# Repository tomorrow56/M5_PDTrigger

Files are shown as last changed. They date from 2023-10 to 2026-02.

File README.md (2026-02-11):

# PD Trigger Module for M5Stack

**[English Version](README_EN.md)**

## 概要

このモジュールは、USB PD（Power Delivery）プロトコルに対応した電源から電力を供給し、電流を監視・制御するためのM5Stack Core/Core2用の拡張モジュールです。
M-Busに接続することで、USB PD対応電源からの電力供給と電流監視を可能にします。

### プリント基板

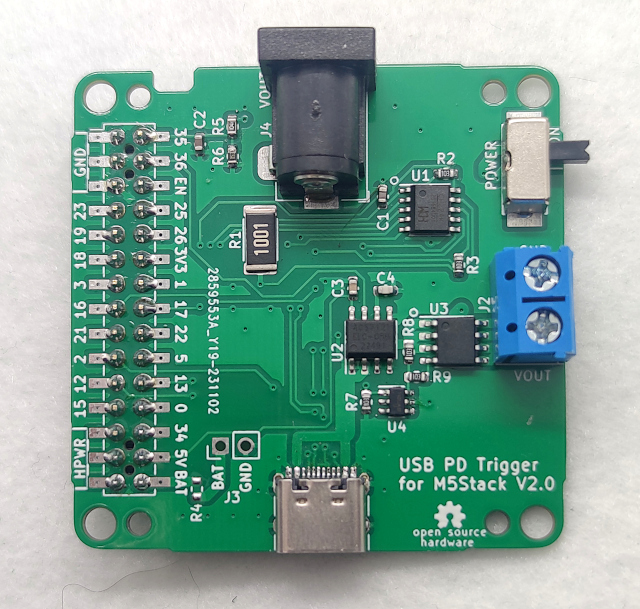
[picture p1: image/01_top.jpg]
Top View

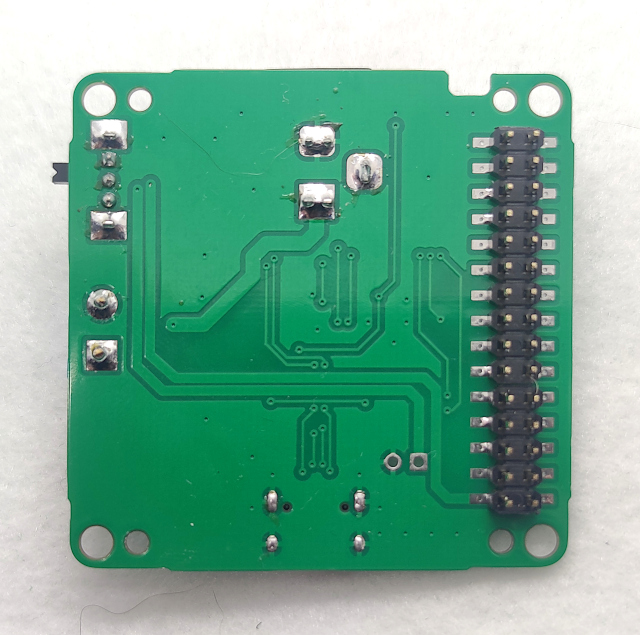
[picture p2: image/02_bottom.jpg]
Bottom View


## 主な機能

### USB PD対応充電器やモバイルバッテリーからの任意電圧の取り出し

WCH社のUSB PDシンクIC 「CH224K」を使用、M5Stack Basic/Core2のM-Busに接続して充電器のPDOに応じて「5V/9V/12V/15V/20V」が取り出せます。(注: PPSには未対応です。)

### 出力電流の測定

ALLEGRO社のホール電流センサIC「ACS712」を搭載し、出力電流が測定出来ます。

### 出力制御

Power Mos FETを用いて、M5Stackのプログラムから出力ON/OFFを制御できます。

### 回路図

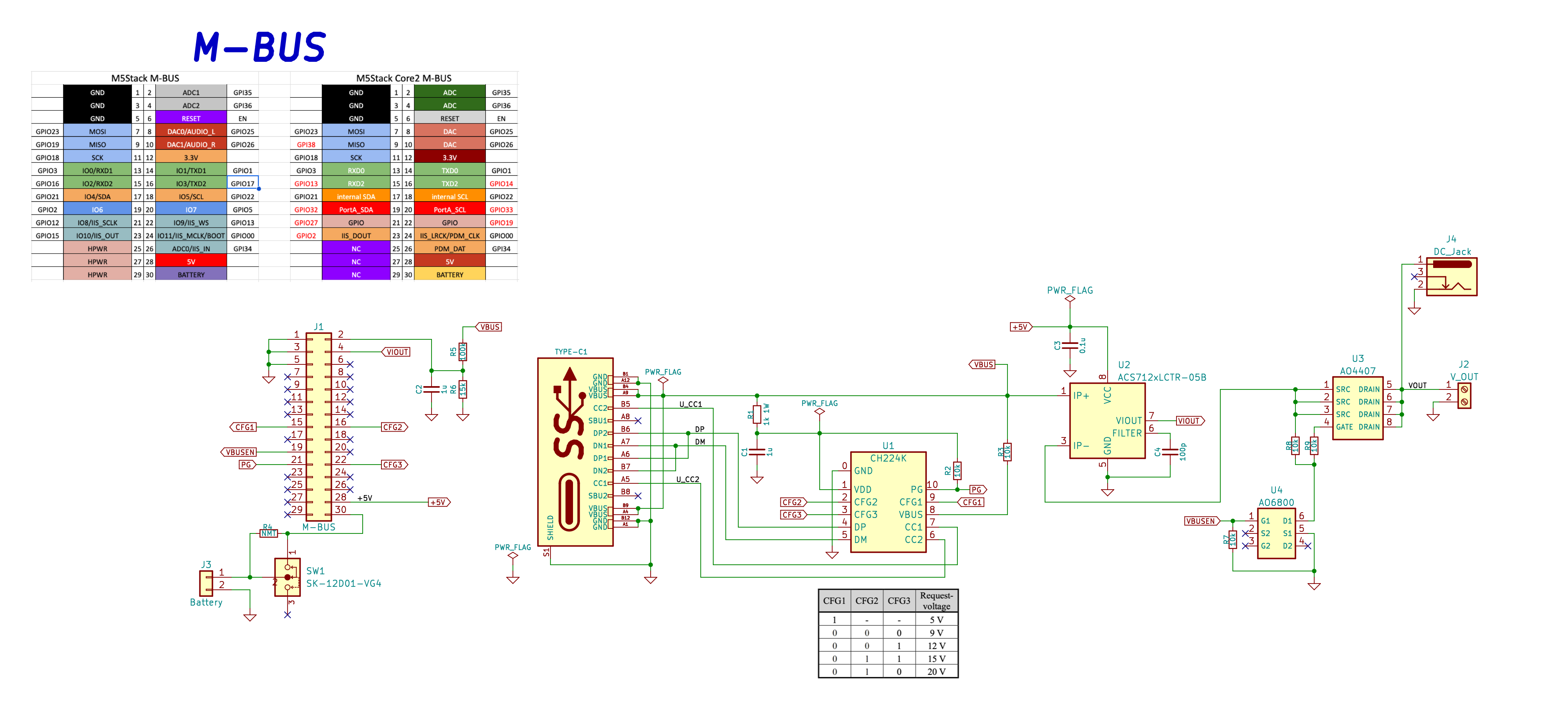
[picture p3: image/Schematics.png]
Schematic


## 使用している主要部品のデータシート

### USB PD Sink IC
[WCH CH224K](https://datasheet.lcsc.com/lcsc/2204251615_WCH-Jiangsu-Qin-Heng-CH224K_C970725.pdf)

### Hall Effect-Based Linear Current Sensor IC
[Allegro ACS712ELCTR-05B-T](https://datasheet.lcsc.com/lcsc/1811061527_Allegro-MicroSystems--LLC-ACS712ELCTR-05B-T_C44471.pdf)

### P-Channel MOSFET
[KEXIN AO4407](https://datasheet.lcsc.com/lcsc/1912111437_KEXIN-AO4407_C382328.pdf)

### Dual N-Channel MOSFET
[UMW AO6800](https://datasheet.lcsc.com/lcsc/2304120930_UMW-Youtai-Semiconductor-Co---Ltd--AO6800_C5375979.pdf)

## フォルダ構成

```text
M5_PDTrigger/
├── README.md              # プロジェクト説明
├── LICENSE                # MITライセンス
├── .gitignore            # Git除外ファイル
├── bom/                  # 部品表
│   └── M5_PDTrigger_BOM.csv
├── case/                 # 3Dプリント用ケース
│   └── PDtrigger_10mm_DC.stl
├── examples/             # サンプルコード
│   ├── M5_PDtrigger_test/
│   │   └── M5_PDtrigger_test.ino
│   └── M5Core2_PDtrigger_test/
│       └── M5Core2_PDtrigger_test.ino
├── image/                # 画像ファイル
│   ├── 01_top.jpg        # 基板表面
│   ├── 02_bottom.jpg     # 基板裏面
│   ├── 03_case_1.jpg     # ケース上面
│   ├── 04_case_2.jpg     # ケース下面
│   ├── 05_terminal.jpg   # 出力端子
│   ├── Sample_basic.jpg  # Basic動作例
│   ├── Sample_core2.jpg  # Core2動作例
│   ├── M5_PDTrigger_BOM.png
│   └── Schematics.png
└── schematics/           # 回路図
    └── M5PD_ch224k_sch.pdf
```

## サンプルコード

M5Stack Basic/Core用のサンプルコードです。以下の機能を実装しています：

### M5Stack Basic用サンプル

- **電圧切り替え**: ボタンA/Cで5V/9V/12V/15V/20VのPDOを切り替え
- **出力制御**: ボタンBで出力ON/OFFを制御  
- **電流電圧監視**: ACS712で電流を、ADコンバータで電圧を測定
- **PG監視**: Power Good信号の状態を表示

**ピン配置**:
```cpp
#define VBUS_I          35    // 電圧測定
#define VI_I            36    // 電流測定  
#define CFG1_O          16    // PD設定1
#define CFG2_O          17    // PD設定2
#define CFG3_O          13    // PD設定3
#define VBUSEN_O         2    // 出力イネーブル
#define PG_I            12    // Power Good入力
```

**操作方法**:
- ボタンA: PDO電圧を下げる
- ボタンB: 出力ON/OFF切り替え
- ボタンC: PDO電圧を上げる

**M5Stack Basicの動作例**:

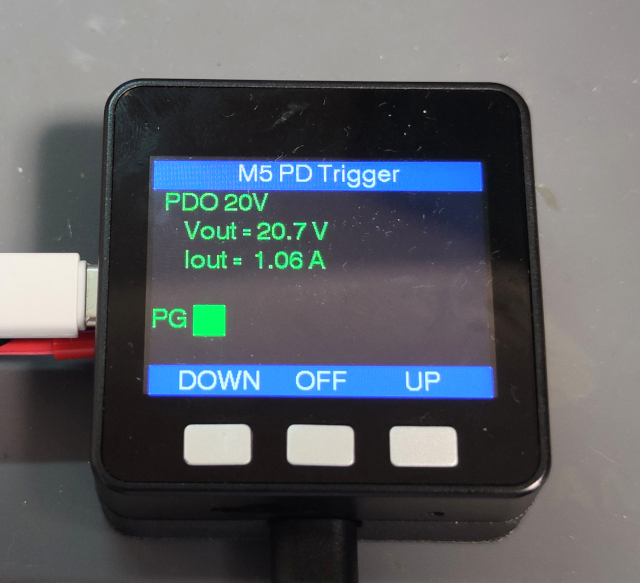
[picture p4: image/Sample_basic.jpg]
Sample_basic


### M5Stack Core2用サンプル

M5Stack Core2用のサンプルコードです。Basic版と同様の機能ですが、ピン配置が異なります：

**ピン配置**:
```cpp
#define VBUS_I          35    // 電圧測定
#define VI_I            36    // 電流測定
#define CFG1_O          13    // PD設定1  
#define CFG2_O          14    // PD設定2
#define CFG3_O          19    // PD設定3
#define VBUSEN_O        32    // 出力イネーブル
#define PG_I            27    // Power Good入力
```
**M5Stack Core2の動作例**:

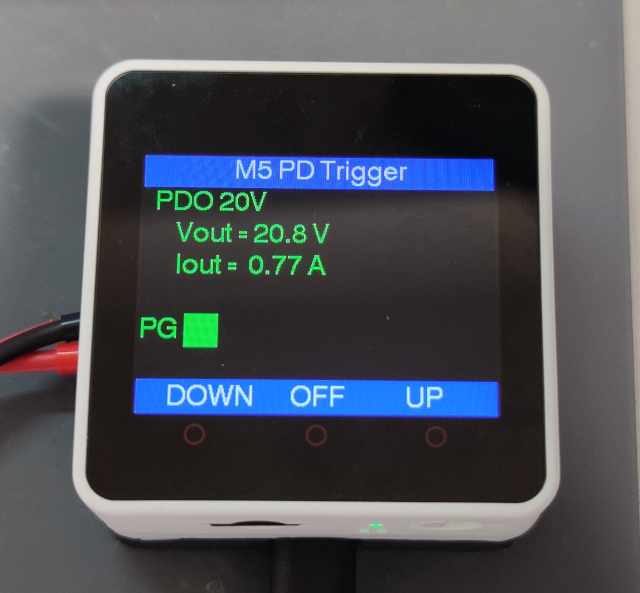
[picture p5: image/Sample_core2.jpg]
Sample_core2


**キャリブレーション**:

* 出力OFFの時に自動で0Aの補正を行います。
* ADコンバータのバラツキを補正するためのキャリブレーションパラメータがありますので、正確な値が必要な場合は実際の測定値を元に調整してください：

```cpp
float vScale = 7.83;     // 電圧スケール係数
float vi_0A = 2.44;      // 0A時の電流センサ出力電圧
float vi_2A = 2.85;      // 2A時の電流センサ出力電圧
```

## ケースに入れた状態

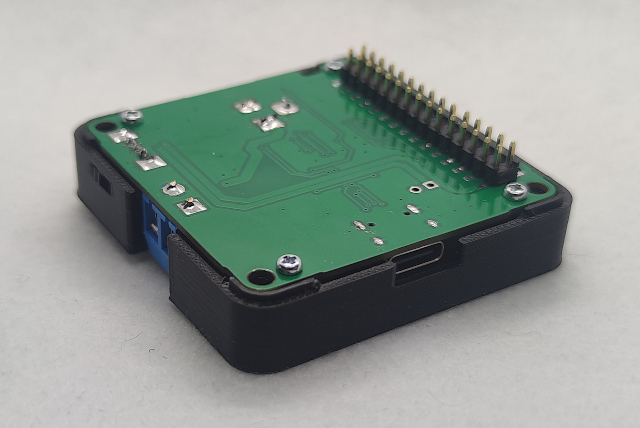
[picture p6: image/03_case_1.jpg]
case_top


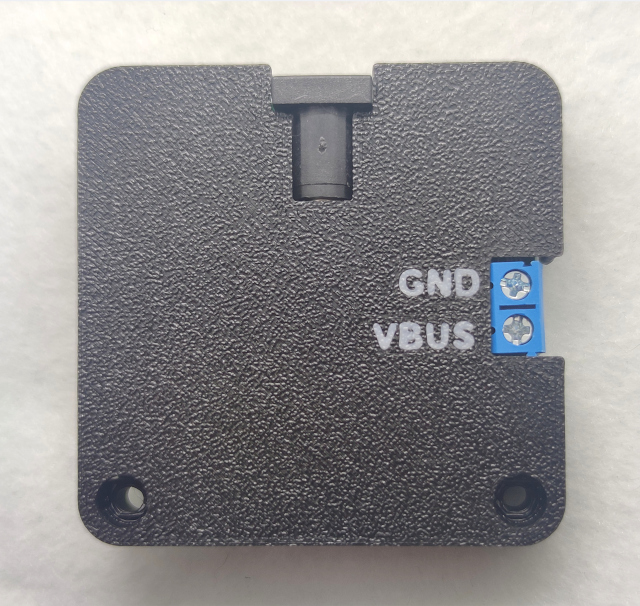
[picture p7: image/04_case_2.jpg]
case_bottom


### 出力端子

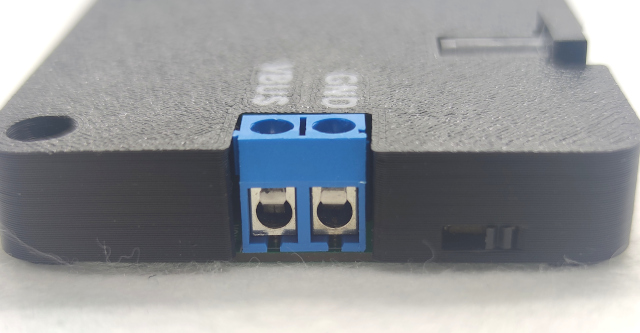
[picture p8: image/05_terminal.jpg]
output_terminals


## ライセンス

本プロジェクトはMITライセンスの下で公開されています。詳細はLICENSEファイルを参照してください。

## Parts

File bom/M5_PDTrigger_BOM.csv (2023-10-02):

No. | Name | フットプリント | 員数 | Type/Name | Link
C1,C2 | チップキャパシタ m1608(i0603) | C_0603_1608Metric | 2 | 1u
C3 | チップキャパシタ m1608(i0603) | C_0603_1608Metric | 1 | 0.1u
C4 | チップキャパシタ m1608(i0603) | C_0603_1608Metric | 1 | 100p
D1 | ショットキーバリアダイオード 40V3A | D_SMA | 1 | NMT | https://akizukidenshi.com/catalog/g/gI-06124/
J1 | ロープロファイルピンヘッダ 2×20(40P) 7.7mm | Pin_Header_MBUS_SMD_TH | 1 | M-BUS | https://akizukidenshi.com/catalog/g/gC-10460/
J2 | ターミナルブロック 2P 青 縦 小 | TB111-2-2 | 1 | TB111-2-2-U-1-1 | https://akizukidenshi.com/catalog/g/gP-01306/
J3 | LiPo接続用 | PinHeader_1x02_P2.54mm_Horizontal | 1 | NMT | https://akizukidenshi.com/catalog/g/gC-15510/
R1 | チップ抵抗 6432 2W 1kΩ | R_2512_6332Metric | 1 | RPS2512F1K | https://akizukidenshi.com/catalog/g/gR-09461/
R2,R3,R8,R9,R7 | チップ抵抗 m1608(i0603) | R_0603_1608Metric | 5 | 10k
R4 | チップ抵抗 m1608(i0603) | R_0603_1608Metric | 1 | NMT
R5 | チップ抵抗 m1608(i0603) | R_0603_1608Metric | 1 | 100k
R6 | チップ抵抗 m1608(i0603) | R_0603_1608Metric | 1 | 15k
SW1 | スライドスイッチ 1回路2接点 基板用 横向き | slide_switch_angled | 1 | SK-12D11VG3 | https://akizukidenshi.com/catalog/g/gP-15703/
TYPE-C1 | USB Type-Cコネクタ基板用 | USB_C_Receptacle_HRO_TYPE-C-31-M-12 | 1 | TYPE-C-31-M-12 | https://akizukidenshi.com/catalog/g/gC-14356/
U1 | USB PD受電プロトコルIC | ESSOP-10_3.9x4.9mm_P1.00mm_ThermalVia | 1 | CH224K | https://akizukidenshi.com/catalog/g/gI-18023/
U2 | 電流センサーIC | SOIC-8_3.9x4.9mm_P1.27mm | 1 | ACS712ELCTR-05B-T | https://www.lcsc.com/product-detail/_Allegro-MicroSystems-LLC-_C44471.html
U3 | P-Channel SOP-8 MOSFETs | SOP-8_3.9x4.9mm_P1.27mm | 1 | AO4407 | https://www.lcsc.com/product-detail/_KEXIN-_C382328.html
U4 | N-Channel SOT-23-6 MOSFETs | SOT-23-6 | 1 | AO6800 | https://www.lcsc.com/product-detail/_UMW-Youtai-Semiconductor-Co-Ltd-_C5375979.html

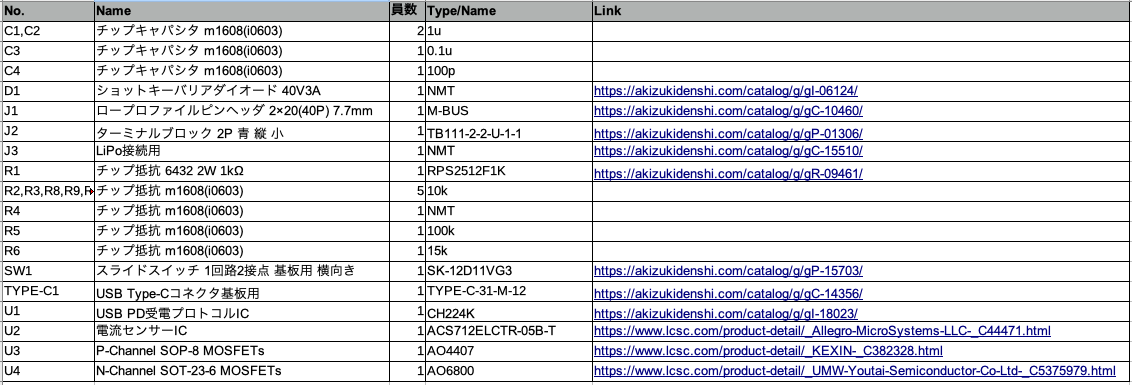
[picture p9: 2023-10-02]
image/M5_PDTrigger_BOM.png

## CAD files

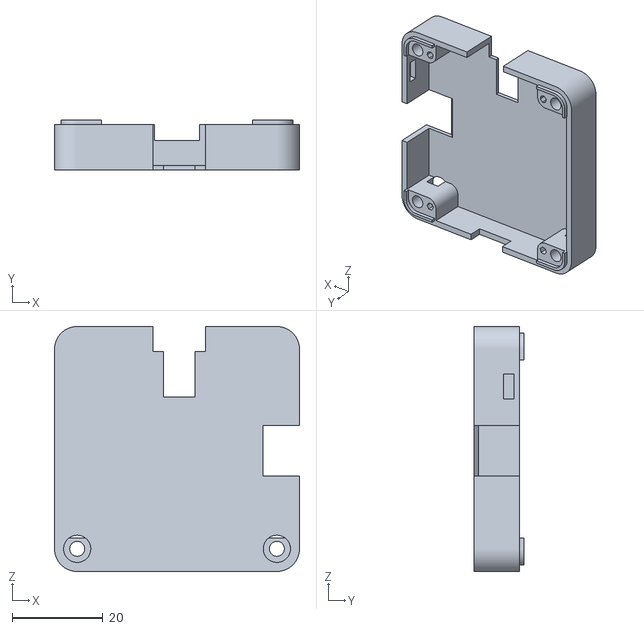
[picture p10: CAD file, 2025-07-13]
case/PDtrigger_10mm_DC.stl
54.0 x 11.0 x 54.0

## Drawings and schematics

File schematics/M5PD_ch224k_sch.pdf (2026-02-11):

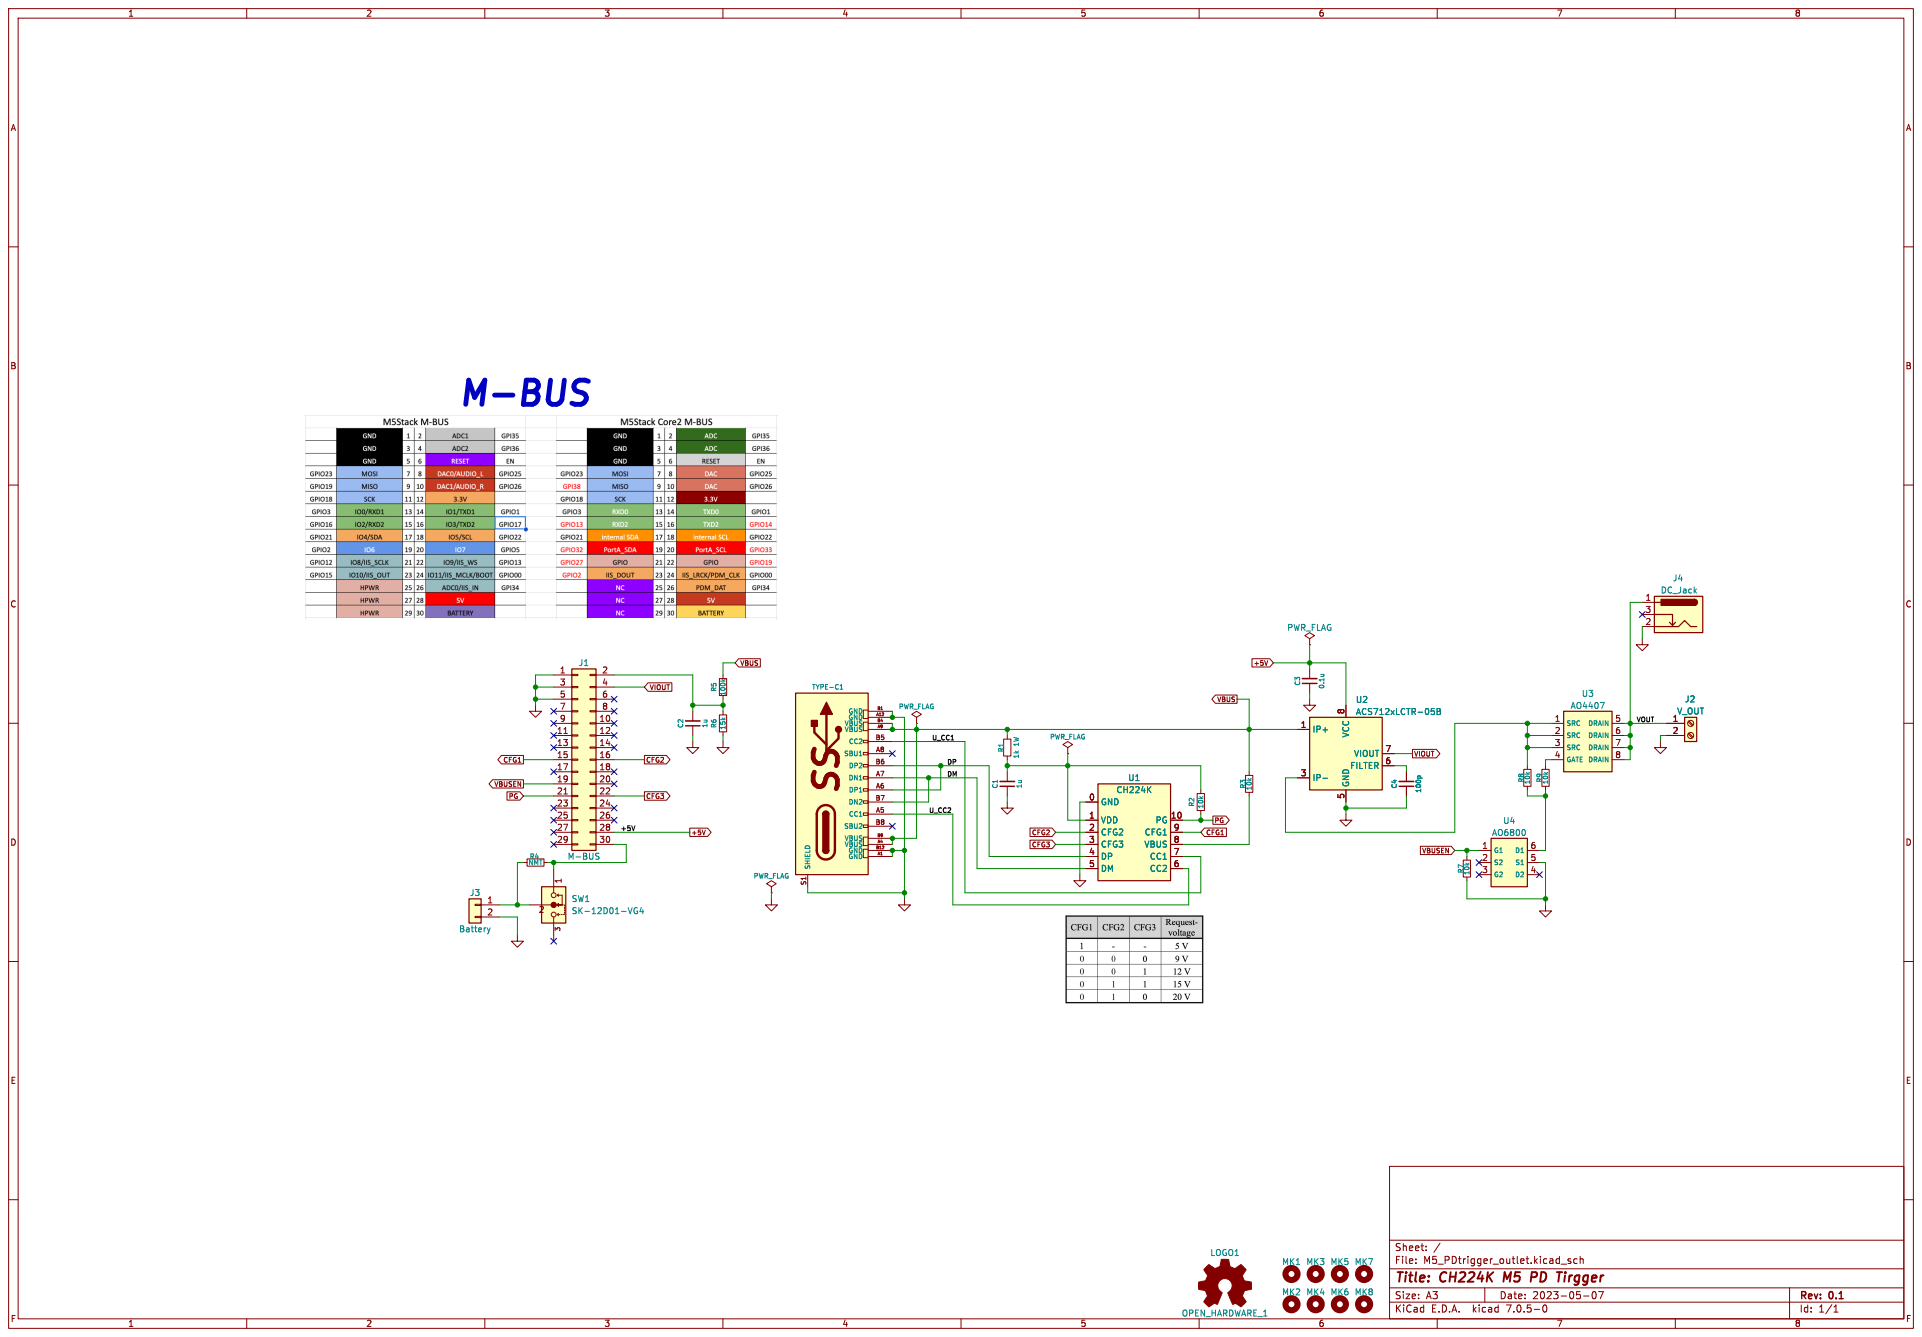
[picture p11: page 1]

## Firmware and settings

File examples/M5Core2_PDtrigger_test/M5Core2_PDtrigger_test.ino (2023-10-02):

/***************************************************
 * M5Core2 PD Trigger (CH224K & ACS712xLCTR-05B)
 * 2023/09/10
 * Copyright(c) @tomorrow56 all rights reserved
****************************************************/

#include <M5Core2.h>
//#include "M5StackUpdater.h"

//fot calibration parameter measurement
//#define CALIBRATE

// M5Stack Pin config
// no PSRAM model only 
/*
#define VBUS_I          35
#define VI_I            36
#define CFG1_O          16
#define CFG2_O          17
#define CFG3_O          13
#define VBUSEN_O         2
#define PG_I            12
*/

// M5Stack Core2 Pin config
#define VBUS_I          35
#define VI_I            36
#define CFG1_O          13
#define CFG2_O          14
#define CFG3_O          19
#define VBUSEN_O        32
#define PG_I            27

/***********
CFG Pin Settig
 +----+----+----+-----+
 |CFG1|CFG2|CFG3| OUT |
 +----+----+----+-----+
 |  1 |  - |  - |   5V|
 |  0 |  0 |  0 |   9V|
 |  0 |  0 |  1 |  12V|
 |  0 |  1 |  1 |  15V|
 |  0 |  1 |  0 |  20V|
 +----+----+----+-----+
***********/

/**********
* Calibration parameter
* Changed to match actual measurements with your equipment
**********/
float vScale = 7.83;  // actual VBUS/VBUS_I
float vi_0A = 2.36;  // VI_I(V) @ 0A output
float vi_2A = 2.76;  // VI_I(V) @ 2A output
float vi_0cal = vi_0A;
float   vbus_i_temp[20];  // for moving average

uint8_t PDO = 0;
bool OE = false;

uint32_t updateTime = 0;       // time for next update
uint8_t interval = 100;  // Update interval

/*
#define CURRENT_100MA  (0x01 << 0)
#define CURRENT_200MA  (0x01 << 1)
#define CURRENT_400MA  (0x01 << 2)
#define CURRENT_800MA  (0x01 << 3)
#define CURRENT_1600MA  (0x01 << 4)
*/

void setup(void) {
  // M5Stack::begin(LCDEnable, SDEnable, SerialEnable, I2CEnable);
  M5.begin(true, true, true, true);
//  M5.Power.begin();
//  M5.Power.setVinMaxCurrent(CURRENT_100MA);

/*
  if(digitalRead(BUTTON_A_PIN) == 0) {
    Serial.println("Will Load menu binary");
    updateFromFS(SD);
    ESP.restart();
  }
*/

  // Pin initialize
  pinMode(VBUS_I, INPUT);
  pinMode(VI_I, INPUT);
  pinMode(PG_I, INPUT);

  pinMode(CFG1_O, OUTPUT);
  pinMode(CFG2_O, OUTPUT);
  pinMode(CFG3_O, OUTPUT);
  pinMode(VBUSEN_O, OUTPUT);

  // Set PD5V
  digitalWrite(CFG1_O, HIGH); 
  digitalWrite(CFG2_O, LOW); 
  digitalWrite(CFG3_O, LOW);
  PDO = 0;
  // Output disable
  digitalWrite(VBUSEN_O, LOW); 
  OE = false;

  // M5.Lcd.setRotation(1);
  M5.Lcd.fillScreen(TFT_BLACK);
  drawTitle("M5 PD Trigger");
  drawBtnMenu("DOWN", "ON", "UP");
  M5.Lcd.setTextColor(TFT_WHITE, TFT_BLACK);

  for(int i = 0; i < 20; i++){
    vbus_i_temp[i] = readVoltage(analogRead(VI_I));
    delay(20);
  }

  vi_0cal = averageVI();

  updateTime = millis(); // Next update time
}

void loop() {
  float vbus_v;
  float vbus_i;
  char buf1[5];
  char buf2[5];

  M5.update();

  if (updateTime <= millis()) {
    updateTime = millis() + interval; // Update interval

    vbus_v = readVoltage(analogRead(VBUS_I)) * vScale;  // read data from CH1
//    vbus_i = (readVoltage(analogRead(VI_I)) - vi_0A) / ((vi_2A - vi_0A) / 2);    // read data from CH2
    // 20 moving averages
    for(int i = 19; i > 0; i--){
      vbus_i_temp[i] = vbus_i_temp[i - 1];
    }
    vbus_i_temp[0]= readVoltage(analogRead(VI_I));    // read data from CH2
    vbus_i = (averageVI() - vi_0cal) / ((vi_2A - vi_0A) / 2);
    
    #ifndef CALIBRATE
      dtostrf(vbus_v,4,1,buf1);
      drawText("Vout = " + (String)buf1 + " V    ", 1, 0);
      Serial.printf("Vout = %s V\n", buf1);

      dtostrf(vbus_i,5,2,buf2);
      drawText("Iout = " + (String)buf2 + " A    ", 1, 1);
      Serial.printf("Iout = %s A\n", buf2);
    #else
      drawText("Vout(raw) = " + (String)readVoltage(analogRead(VBUS_I)) + " V    ", 1, 0);
      Serial.println("Vout(raw) = " + (String)readVoltage(analogRead(VBUS_I)) + " V");

      drawText("Iout(raw) = " + (String)readVoltage(analogRead(VI_I)) + " V    ", 1, 1);
      Serial.println("Iout(raw) = " + (String)readVoltage(analogRead(VI_I)) + " V");
    #endif


    switch(PDO){
      case 0:
      digitalWrite(CFG1_O, HIGH); 
      digitalWrite(CFG2_O, LOW); 
      digitalWrite(CFG3_O, LOW);
      drawSubTitle("PDO 5V    ");
      break;
      case 1:
      digitalWrite(CFG1_O, LOW); 
      digitalWrite(CFG2_O, LOW); 
      digitalWrite(CFG3_O, LOW);
      drawSubTitle("PDO 9V    ");
      break;
      case 2:
      digitalWrite(CFG1_O, LOW); 
      digitalWrite(CFG2_O, LOW); 
      digitalWrite(CFG3_O, HIGH);
      drawSubTitle("PDO 12V    ");
      break;
      case 3:
      digitalWrite(CFG1_O, LOW); 
      digitalWrite(CFG2_O, HIGH); 
      digitalWrite(CFG3_O, HIGH);
      drawSubTitle("PDO 15V    ");
      break;
      case 4:
      digitalWrite(CFG1_O, LOW); 
      digitalWrite(CFG2_O, HIGH); 
      digitalWrite(CFG3_O, LOW);
      drawSubTitle("PDO 20V    ");
      break;
      default:
      digitalWrite(CFG1_O, HIGH); 
      digitalWrite(CFG2_O, LOW); 
      digitalWrite(CFG3_O, LOW);
      drawSubTitle("PDO 5V    ");
      break;
    }

    if(OE == true){
      digitalWrite(VBUSEN_O, HIGH);
      Serial.println("Output Enabled");
    }else{
      digitalWrite(VBUSEN_O, LOW); 
      Serial.println("Output Disabled");
      vi_0cal = averageVI();
     }
    
    drawText("PG", 0, 3);
    if(vbus_v >= 3){
      if(digitalRead(PG_I) == LOW){
        M5.Lcd.fillRect(40, 150, 30, 30, TFT_GREEN);
        Serial.println("PG OK");
      }else{
        M5.Lcd.fillRect(40, 150, 30, 30, TFT_RED);
        Serial.println("PG NG");
      }
    }else{
      M5.Lcd.fillRect(40, 150, 30, 30, TFT_BLACK);
      M5.Lcd.drawRect(40, 150, 30, 30, TFT_WHITE);
    }

  }

  if(M5.BtnA.wasPressed()){
    if(PDO > 0){
      PDO--;
    }
  }

  if(M5.BtnB.wasPressed()){
    if(OE == false){
      OE = true;
      drawBtnMenu("DOWN", "OFF", "UP");
      M5.Lcd.setTextColor(TFT_GREEN, TFT_BLACK);
    }else{
      OE = false;
      drawBtnMenu("DOWN", "ON", "UP");
      M5.Lcd.setTextColor(TFT_WHITE, TFT_BLACK);
    }
  }

  if(M5.BtnC.wasPressed()){
    if(PDO < 4){
      PDO++;
    }
  }
}

void drawTitle(String Title){
  M5.Lcd.setTextSize(1);
  M5.Lcd.fillRect(0, 0, 320, 30, TFT_BLUE);
  M5.Lcd.setTextColor(TFT_WHITE, TFT_BLUE);
  M5.Lcd.drawCentreString(Title, 160, 2, 4);
}

void drawSubTitle(String SubTitle){
  M5.Lcd.setTextSize(1);
  M5.Lcd.drawString(SubTitle, 10, 33, 4);
}

void drawText(String Text, int xPos, int yPos){
  M5.Lcd.setTextSize(1);
  M5.Lcd.drawString(Text, xPos * 30, yPos * 30 + 60 + 3, 4);
}

void drawBtnMenu(String A, String B, String C){
  M5.Lcd.setTextSize(1);
  M5.Lcd.fillRect(0, 210, 320, 30, TFT_BLUE);
  M5.Lcd.setTextColor(TFT_WHITE, TFT_BLUE);
  M5.Lcd.drawCentreString(A, 65, 214, 4);
  M5.Lcd.drawCentreString(B, 160, 214, 4);
  M5.Lcd.drawCentreString(C, 255, 214, 4);
}

float readVoltage(uint16_t Vread){
  float Vdc;
  // Convert the read data into voltage
  if(Vread < 5){
    Vdc = 0;
  }else if(Vread <= 1084){
    Vdc = 0.11 + (0.89 / 1084) * Vread;
  }else if(Vread <= 2303){
    Vdc = 1.0 + (1.0 / (2303 - 1084)) * (Vread - 1084);
  }else if(Vread <= 3179){
    Vdc = 2.0 + (0.7 / (3179 - 2303)) * (Vread - 2303);
  }else if(Vread <= 3659){
    Vdc = 2.7 + (0.3 / (3659 - 3179)) * (Vread - 3179);
  }else if(Vread <= 4071){
    Vdc = 3.0 + (0.2 / (4071 - 3659)) * (Vread - 3659);
  }else{
    Vdc = 3.2;
  }
  return Vdc;
}

float averageVI(){
  float vi_sum = 0;
  for(int i = 0; i < 20; i++){
    vi_sum = vi_sum + vbus_i_temp[i];
  }
  return vi_sum / 20;
}

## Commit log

2025-07-13 add New DC Case
    [PDtrigger_10mm_DC.stl]
2026-02-11 Add .gitignore and README_EN.md with folder structure and sample code documentation
    - Create .gitignore for macOS and development files
    - Add English README with complete documentation
    - Update Japanese README with folder structure and sample code details
    - Add cross-links between Japanese and English READMEs
    - Remove macOS metadata files (._*)
    - Add schematics folder with PDF schematic
